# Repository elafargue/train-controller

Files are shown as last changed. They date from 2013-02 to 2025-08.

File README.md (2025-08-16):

train-controller
================

A Z scale model train controller with web interface.

You will find detailed instructions at http://www.aerodynes.org/ . This repository includes both hardware design files and the software you need to build the complete project.

The whole system is working well, and has been running for a long time on an actual layout.

Repository structure:

arduino: arduino sketches for the train controller hardware
hardware: schematics, boards (Eagle)
server: the node.js server that interfaces with the controller and serves the web app

Installation:

Please refer to http://www.aerodynes.org/ for detailed installation instructions. Below is a quick summary:

- Build the cape - Eagle files are included, all components are referenced in the design file, it is fairly straightforward.
- Install the arduino firmware on the cape: you can use the very good "ino" command line interface for doing so.
- Install Ubuntu Linux on your Beaglebone Black
- Install the latest nodejs distribution, and clone this repository
- Install mongodb (Ubuntu package is fine)
- Run "npm install" then "node server.js"
- ... you should be set!

Credits:

Thanks to the creators of the PID and aJson libraries (be sure to use the latest aJson library as I contributed patches to make it more robust).
Thanks to Christophe Coenraets for his great tutorials which were used as a base for the server

License:

All original code is placed under GPLv3 unless stated otherwise, see relevant license files where appropriate.

# Run as a service

Use `resources/train-controller.service` and copy it to `/etc/systemd/system`, then:

```
$ sudo systemctl daemon-reload
$ sudo systemctl enable train-controller
Created symlink /etc/systemd/system/multi-user.target.wants/train-controller.service → /etc/systemd/system/train-controller.service.
$ sudo service train-controller start
```

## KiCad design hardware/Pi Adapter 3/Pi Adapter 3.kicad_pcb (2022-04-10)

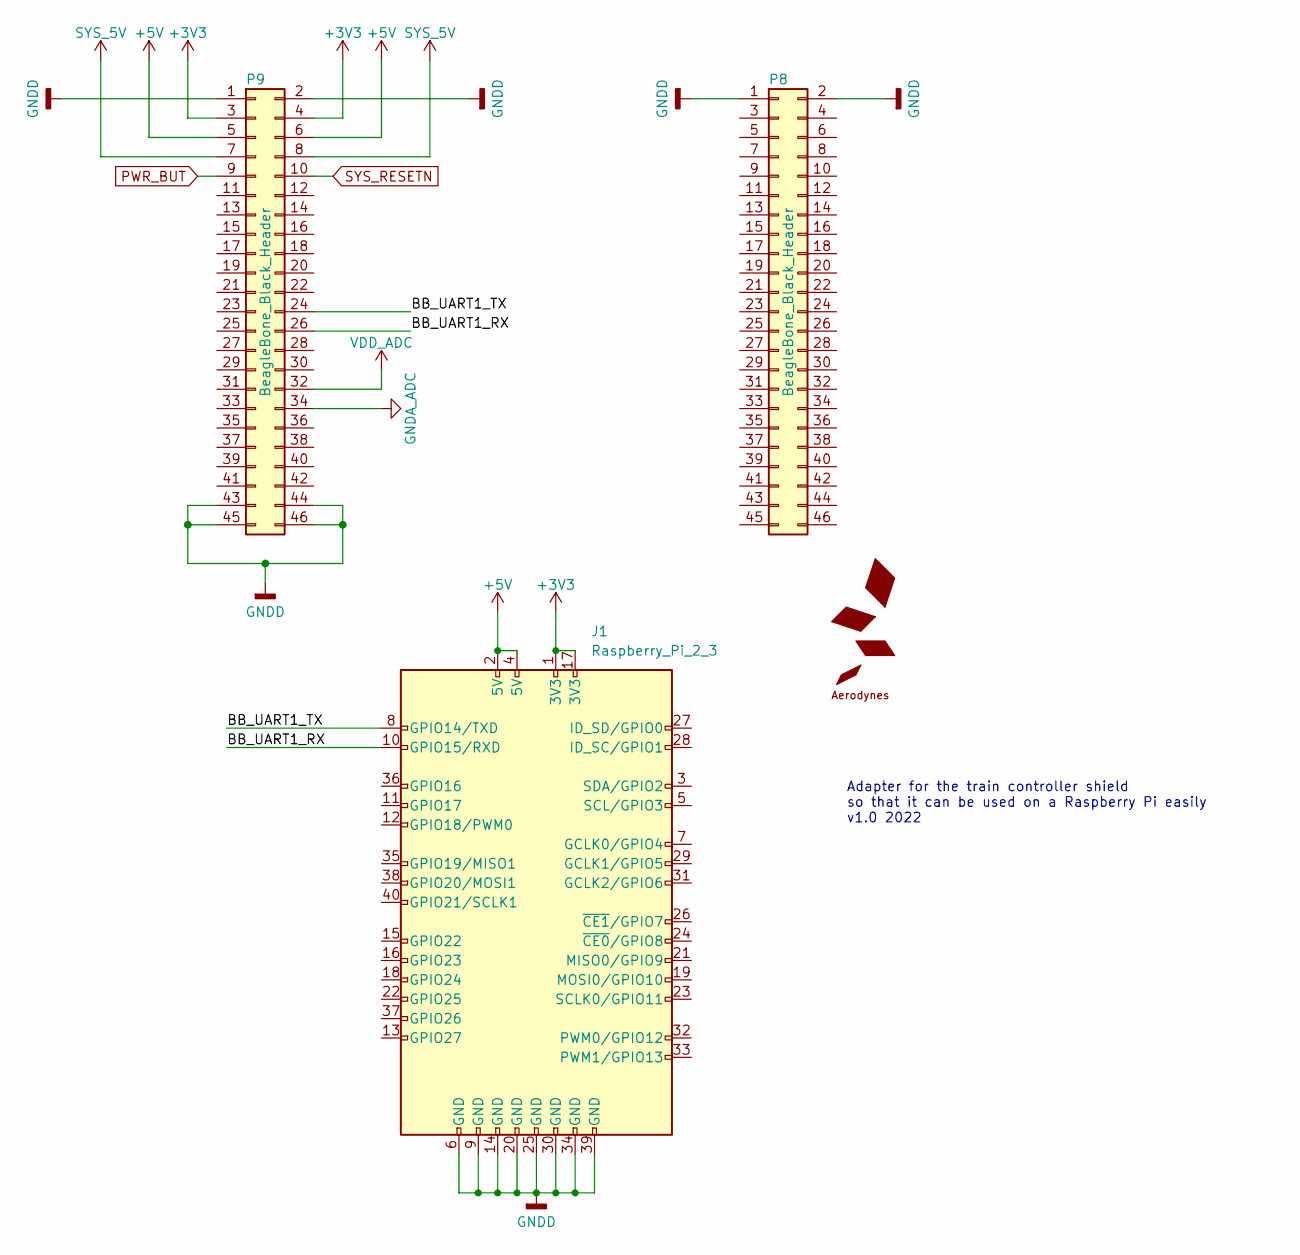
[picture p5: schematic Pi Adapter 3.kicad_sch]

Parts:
J1: Raspberry_Pi_2_3; PinSocket_2x20_P2.54mm_Vertical
M1: LOGO-AERODYNESSMALL; LOGO-AERODYNES-S
P8, P9: BeagleBone_Black_Header; Socket_BeagleBone_Black

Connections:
+3V3: J1.1 (3V3), J1.17 (3V3), P9.3, P9.4
+5V: J1.2 (5V), J1.4 (5V), P9.5, P9.6
/BB_UART1_RX: J1.10 (GPIO15/RXD), P9.26
/BB_UART1_TX: J1.8 (GPIO14/TXD), P9.24
GNDA_ADC: P9.34
GNDD: J1.6 (GND), J1.9 (GND), J1.14 (GND), J1.20 (GND), J1.25 (GND), J1.30 (GND), J1.34 (GND), J1.39 (GND), P8.1, P8.2, P9.1, P9.2, P9.43, P9.44, P9.45, P9.46
PWR_BUT: P9.9
SYS_5V: P9.7, P9.8
SYS_RESETN: P9.10
VDD_ADC: P9.32

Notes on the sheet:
Adapter for the train controller shield so that it can be used on a Raspberry Pi easily v1.0 2022

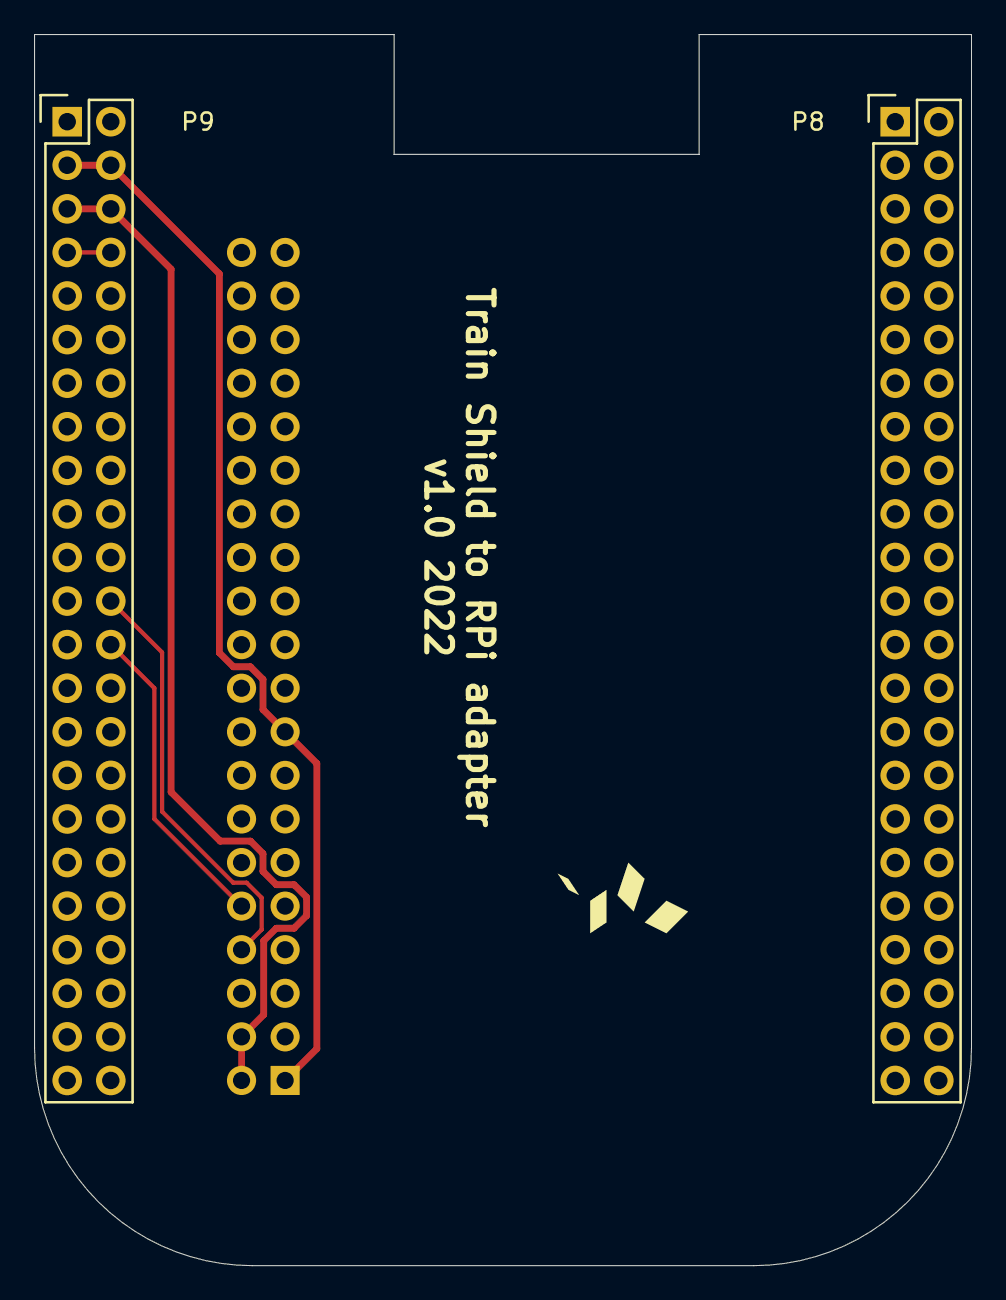
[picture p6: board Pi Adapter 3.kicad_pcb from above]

Board: 2 copper layers, 54.6 x 71.7 mm, 4 parts (1 on the bottom side), 6 nets.

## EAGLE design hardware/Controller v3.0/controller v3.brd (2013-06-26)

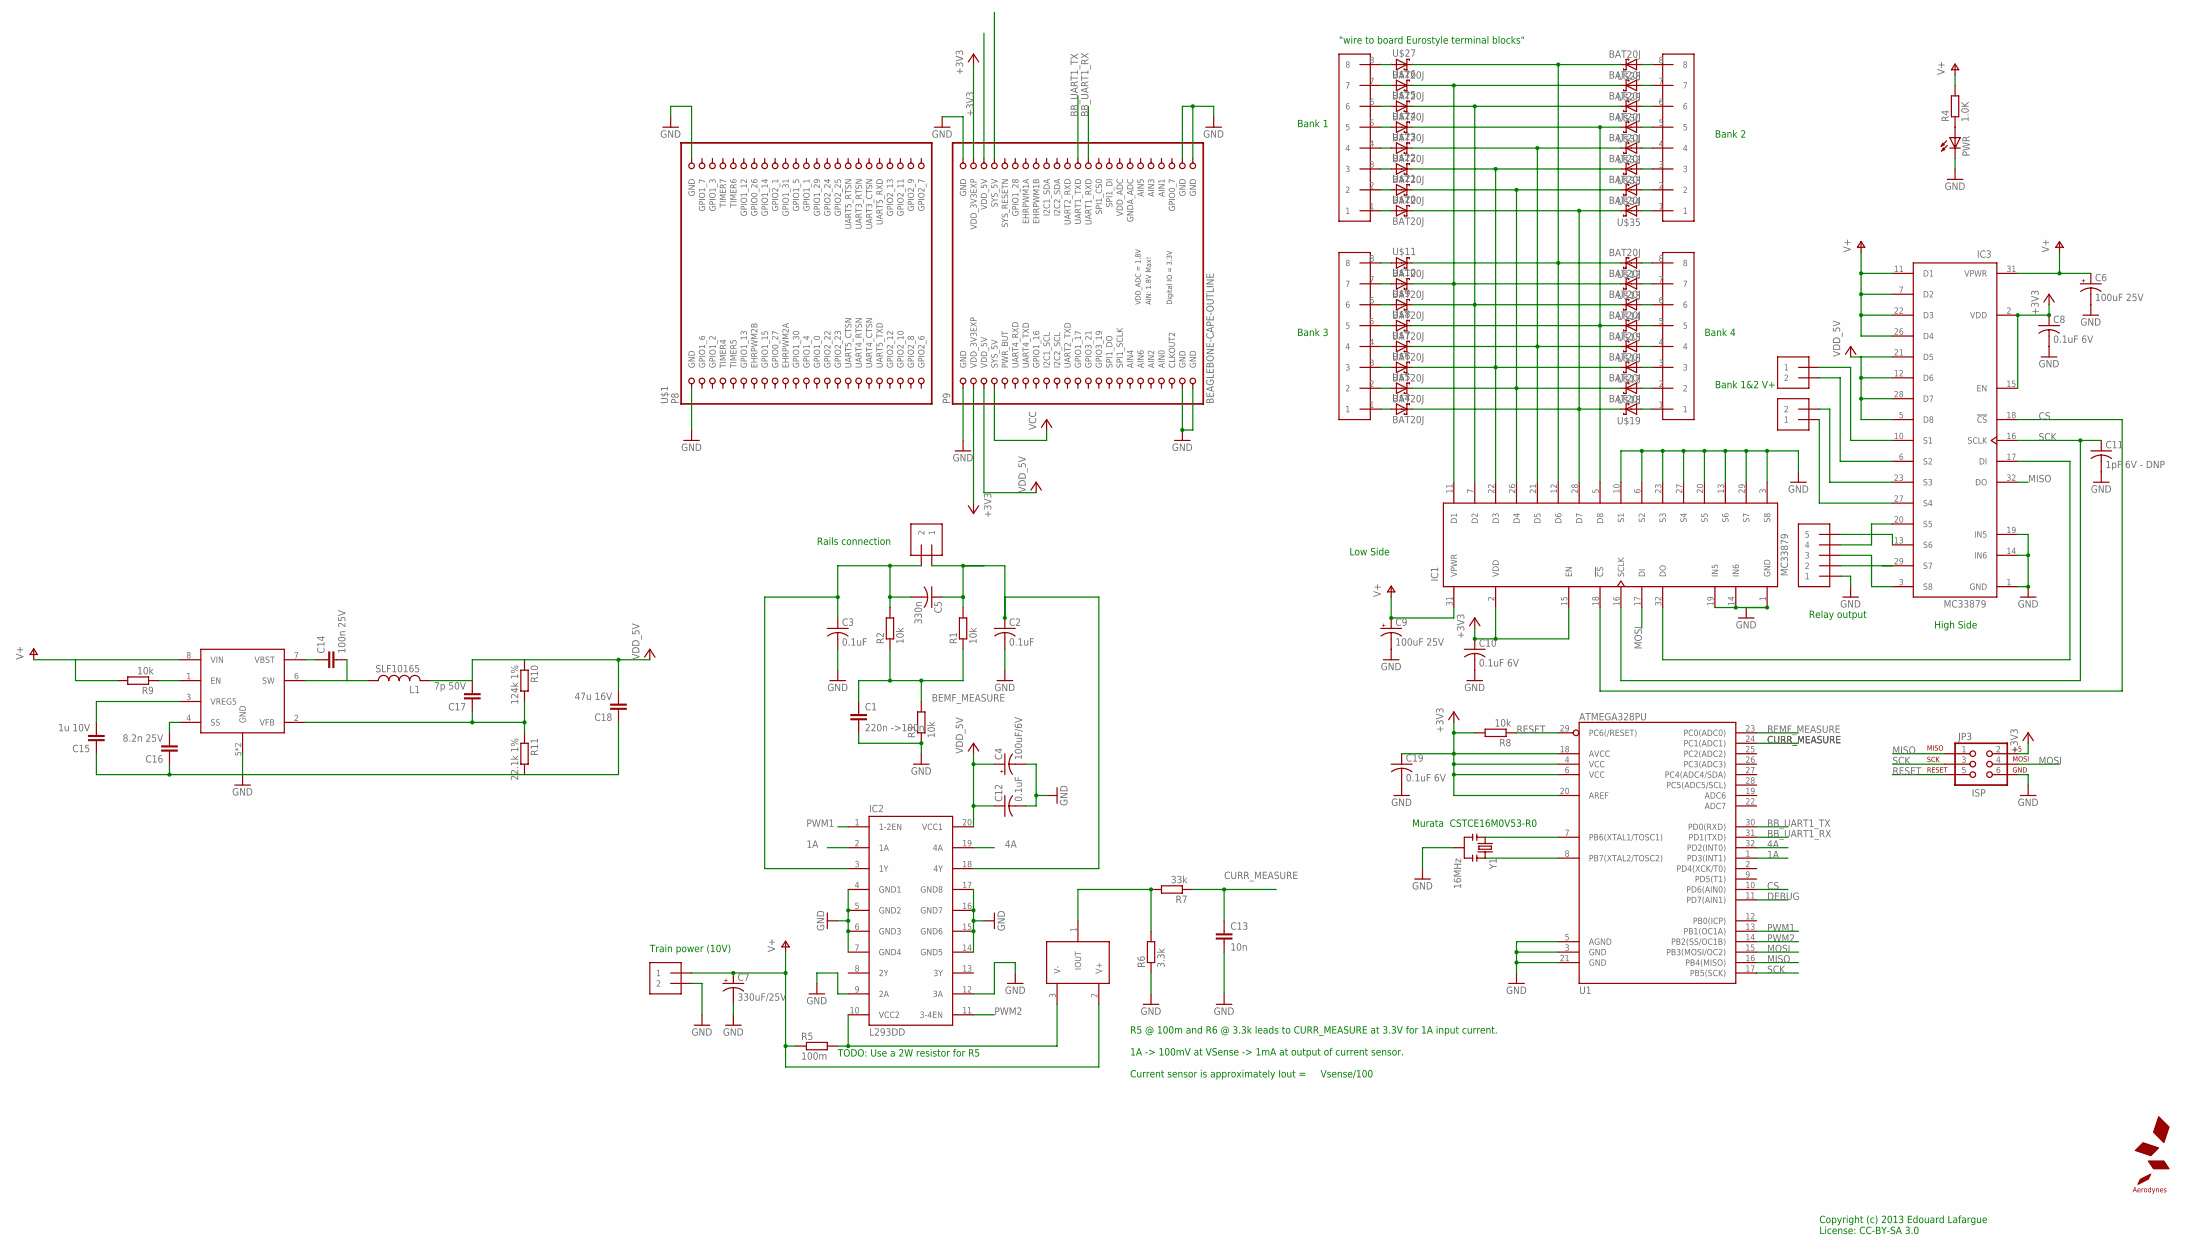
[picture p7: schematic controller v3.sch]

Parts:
BANK12, BANK34: 1X2-3.5MM
C1: 220n ->100n; C0805
C2, C3, C12: 0.1uF; C025-025X050
C4: 100uF/6V; E2,5-5
C5: 330n; C050-025X075
C6, C9: 100uF 25V; E2,5-6E
C7: 330uF/25V; E3,5-8
C8, C10: 0.1uF 6V; C025-025X050
C11: 1pF 6V - DNP; C0805K
C13: 10n; C0805K
C14: 100n 25V; C0805K
C15: 1u 10V; C0603K
C16: 8.2n 25V; C0603K
C17: 7p 50V; C0805K
C18: 47u 16V; C1210K
C19: 0.1uF 6V; C0603K
CON1, CON2, CON3, CON4: 1X08-CONN3.5MM; 1X08-3.5MM
CUR_SENSE: ZXCT1009-F; SOT23-1TOP
IC1, IC3: MC33879; 32SOICW-EP-065PITCH
IC2: L293DD; SOIC20-2
J1: 1X5; 1X05-3.5MM
JP3: ISP; 2X3
L1: SLF10165
PWR: LED3MM
R1, R2, R3, R8, R9: 10k; R0603
R4: 1.0K; R0603
R5: 100m; M1206
R6: 3.3k; R0603
R7: 33k; R0603
R10: 124k 1%; R0603
R11: 22.1k 1%; R0603
SL1, SL2: 1X2-3.5MM
U1: ATMEGA328PU; TQFP32-08
U$1: BEAGLEBONE-CAPE-OUTLINE; BEAGLEBONE_NOCUT
U$2: LOGO-AERODYNESSMALL; LOGO-AERODYNES-S
U$4, U$5, U$6, U$7, U$8, U$9, U$10, U$11, U$12, U$13, U$14, U$15, U$16, U$17, U$18, U$19, U$20, U$21, U$22, U$23, U$24, U$25, U$26, U$27, U$28, U$29, U$30, U$31, U$32, U$33, U$34, U$35: BAT20J; SOD-323F
U$36: TPS54327DDA; SOIC8-DDA
Y1: 16MHz; RESONATOR-SMD

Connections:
1A: IC2.2 (1A), U1.1 (PD3(INT1))
1Y: C3.1, C5.2, IC2.3 (1Y), R2.2, SL1.2
4A: IC2.19 (4A), U1.32 (PD2(INT0))
4Y: C2.1, C5.1, IC2.18 (4Y), R1.2, SL1.1
+3V3: C8.1, C10.1, C19.1, IC1.2 (VDD), IC1.15 (EN), IC3.2 (VDD), IC3.15 (EN), JP3.2, R8.2, U1.4 (VCC), U1.6 (VCC), U1.18 (AVCC), U1.20 (AREF), U$1.P9-3 (VDD_3V3EXP), U$1.P9-4 (VDD_3V3EXP)
BB_UART1_RX: U1.31 (PD1(TXD)), U$1.P9-26 (UART1_RXD)
BB_UART1_TX: U1.30 (PD0(RXD)), U$1.P9-24 (UART1_TXD)
BEMF_MEASURE: C1.1, R1.1, R2.1, R3.2, U1.23 (PC0(ADC0))
CS: IC1.18 (!CS), IC3.18 (!CS), U1.10 (PD6(AIN0))
CURR_MEASURE: C13.1, R7.1, U1.24 (PC1(ADC1))
DEBUG: U1.11 (PD7(AIN1))
GND: C1.2, C2.2, C3.2, C4.-, C6.-, C7.-, C8.2, C9.-, C10.2, C11.2, C12.2, C13.2, C15.1, C16.1, C18.1, C19.2, IC1.1 (GND), IC1.3 (S8), IC1.6 (S2), IC1.10 (S1), IC1.13 (S6), IC1.14 (IN6), IC1.19 (IN5), IC1.20 (S5), IC1.23 (S3), IC1.27 (S4), IC1.29 (S7), IC2.4 (GND1), IC2.5 (GND2), IC2.6 (GND3), IC2.7 (GND4), IC2.9 (2A), IC2.12 (3A), IC2.14 (GND5), IC2.15 (GND6), IC2.16 (GND7), IC2.17 (GND8), IC3.1 (GND), IC3.14 (IN6), IC3.19 (IN5), J1.1, JP3.6, PWR.K (C), R3.1, R6.1, R11.2, SL2.2, U1.3 (GND), U1.5 (AGND), U1.21 (GND), U$1.P8-1 (GND), U$1.P8-2 (GND), U$1.P9-1 (GND), U$1.P9-2 (GND), U$1.P9-43 (GND), U$1.P9-44 (GND), U$1.P9-45 (GND), U$1.P9-46 (GND), U$36.5 (GND), U$36.PAD (GND), Y1.2
GNDA_ADC: U$1.P9-34 (GNDA_ADC)
MISO: IC3.32 (DO), JP3.1, U1.16 (PB4(MISO))
MOSI: IC1.17 (DI), JP3.4, U1.15 (PB3(MOSI/OC2))
unnamed: BANK34.1, IC3.27 (S4)
unnamed: BANK34.2, IC3.23 (S3)
unnamed: BANK12.2, IC3.6 (S2)
unnamed: BANK12.1, IC3.10 (S1)
unnamed: CUR_SENSE.3 (V-), IC2.10 (VCC2), R5.2
unnamed: CUR_SENSE.1 (IOUT), R6.2, R7.2
unnamed: IC1.22 (D3), U$6.C, U$17.C, U$22.C, U$33.C
unnamed: IC1.21 (D5), U$7.C, U$16.C, U$23.C, U$32.C
unnamed: IC1.5 (D8), U$8.C, U$15.C, U$24.C, U$31.C
unnamed: CON3.3, U$6.A
unnamed: IC1.28 (D7), U$4.C, U$19.C, U$20.C, U$35.C
unnamed: IC1.12 (D6), U$11.C, U$12.C, U$27.C, U$28.C
unnamed: IC1.32 (DO), IC3.17 (DI)
unnamed: IC1.11 (D1), U$10.C, U$13.C, U$26.C, U$29.C
unnamed: IC1.26 (D4), U$5.C, U$18.C, U$21.C, U$34.C
unnamed: IC1.7 (D2), U$9.C, U$14.C, U$25.C, U$30.C
unnamed: IC3.20 (S5), J1.4
unnamed: CON3.2, U$5.A
unnamed: CON3.1, U$4.A
unnamed: CON3.8, U$11.A
unnamed: CON3.7, U$10.A
unnamed: CON3.6, U$9.A
unnamed: CON3.5, U$8.A
unnamed: CON3.4, U$7.A
unnamed: CON4.8, U$12.A
unnamed: CON4.7, U$13.A
unnamed: CON4.6, U$14.A
unnamed: CON4.5, U$15.A
unnamed: CON4.4, U$16.A
unnamed: CON4.3, U$17.A
unnamed: CON4.2, U$18.A
unnamed: CON4.1, U$19.A
unnamed: CON1.8, U$27.A
unnamed: CON1.7, U$26.A
unnamed: PWR.A, R4.1
unnamed: CON1.6, U$25.A
unnamed: CON1.5, U$24.A
unnamed: CON1.4, U$23.A
unnamed: CON1.3, U$22.A
unnamed: CON1.2, U$21.A
unnamed: CON1.1, U$20.A
unnamed: CON2.8, U$28.A
unnamed: CON2.7, U$29.A
unnamed: CON2.6, U$30.A
unnamed: CON2.5, U$31.A
unnamed: CON2.4, U$32.A
unnamed: CON2.3, U$33.A
unnamed: CON2.2, U$34.A
unnamed: CON2.1, U$35.A
unnamed: IC3.13 (S6), J1.5
unnamed: IC3.29 (S7), J1.2
unnamed: IC3.3 (S8), J1.3
unnamed: U1.7 (PB6(XTAL1/TOSC1)), Y1.1
unnamed: U1.8 (PB7(XTAL2/TOSC2)), Y1.3
unnamed: R9.1, U$36.1 (EN)
unnamed: C14.1, U$36.7 (VBST)
unnamed: C16.2, U$36.4 (SS)
unnamed: C14.2, L1.P$1 (1), U$36.6 (SW)
unnamed: C15.2, U$36.3 (VREG5)
unnamed: C17.1, R10.2, R11.1, U$36.2 (VFB)
PWM1: IC2.1 (1-2EN), U1.13 (PB1(OC1A))
PWM2: IC2.11 (3-4EN), U1.14 (PB2(SS/OC1B))
RESET: JP3.5, R8.1, U1.29 (PC6(/RESET))
SCK: C11.1, IC1.16 (SCLK), IC3.16 (SCLK), JP3.3, U1.17 (PB5(SCK))
SYS_5V: U$1.P9-7 (SYS_5V), U$1.P9-8 (SYS_5V)
V+: C6.+, C7.+, C9.+, CUR_SENSE.2 (V+), IC1.31 (VPWR), IC3.7 (D2), IC3.11 (D1), IC3.22 (D3), IC3.26 (D4), IC3.31 (VPWR), R4.2, R5.1, R9.2, SL2.1, U$36.8 (VIN)
VDD_5V: C4.+, C12.1, C17.2, C18.2, IC2.20 (VCC1), IC3.5 (D8), IC3.12 (D6), IC3.21 (D5), IC3.28 (D7), L1.P$2 (2), R10.1, U$1.P9-5 (VDD_5V), U$1.P9-6 (VDD_5V)
VDD_ADC: U$1.P9-32 (VDD_ADC)

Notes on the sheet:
Rails connection
Train power (10V)
Low Side
High Side
Bank 1
Bank 2
Bank 1&2 V+
Bank 3
Bank 4
"wire to board Eurostyle terminal blocks"
R5 @ 100m and R6 @ 3.3k leads to CURR_MEASURE at 3.3V for 1A input current. 1A -> 100mV at VSense -> 1mA at output of current sensor. Current sensor is approximately Iout = Vsense/100
Copyright (c) 2013 Edouard Lafargue License: CC-BY-SA 3.0
TODO: Use a 2W resistor for R5
Relay output
Murata CSTCE16M0V53-R0

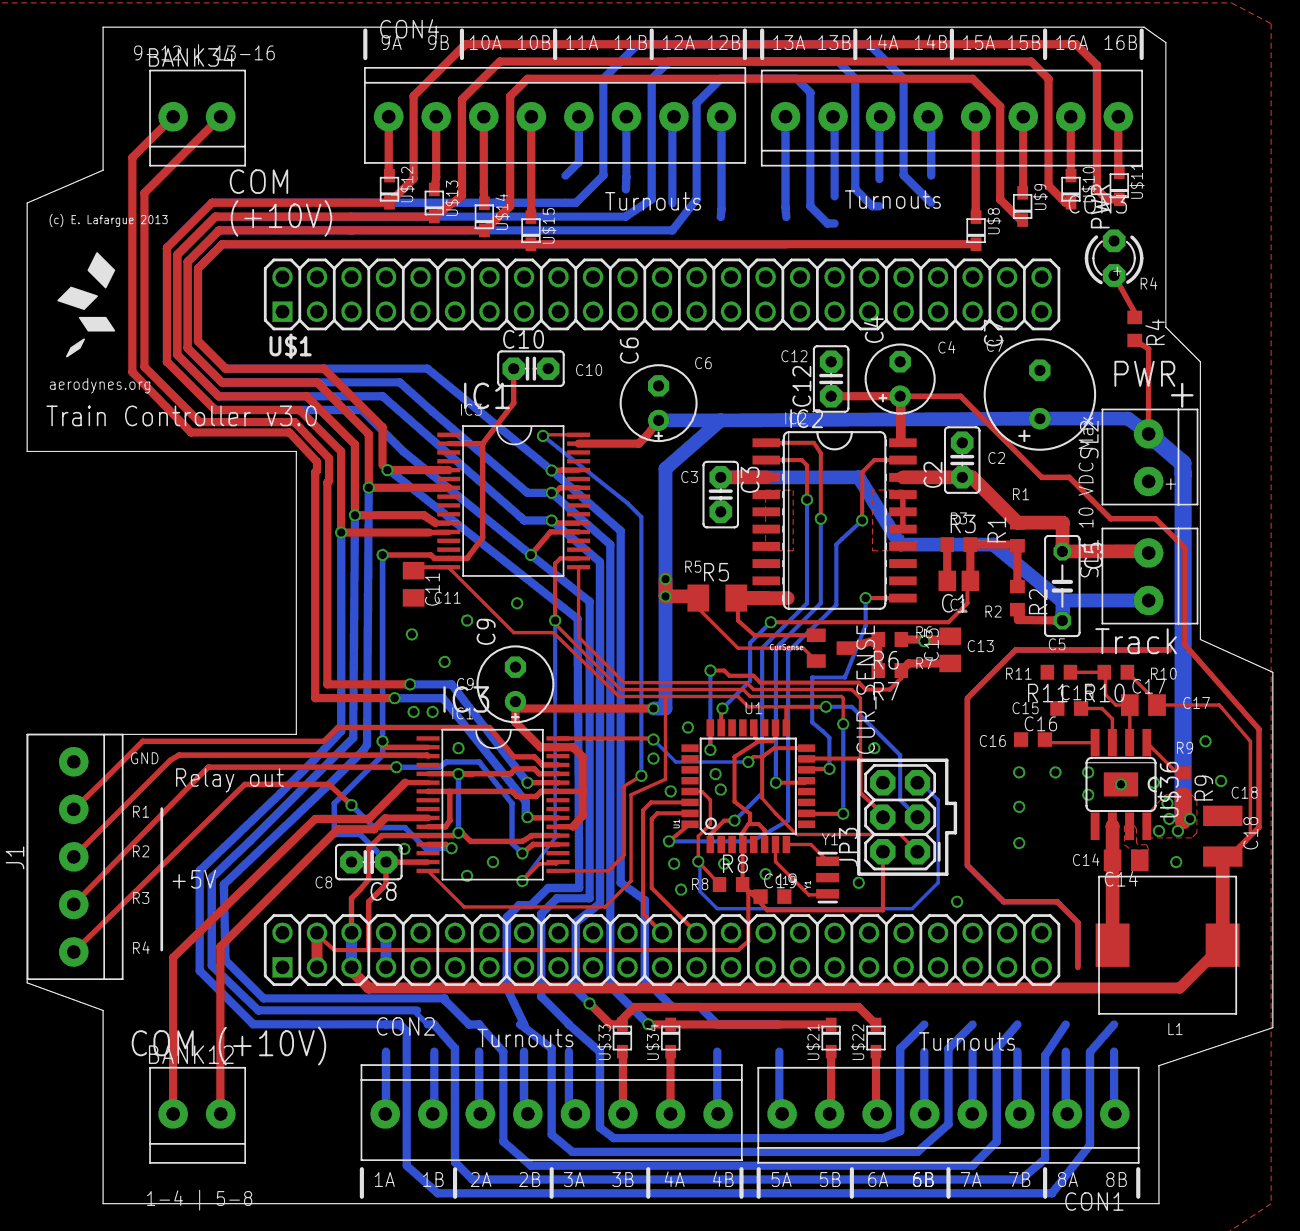
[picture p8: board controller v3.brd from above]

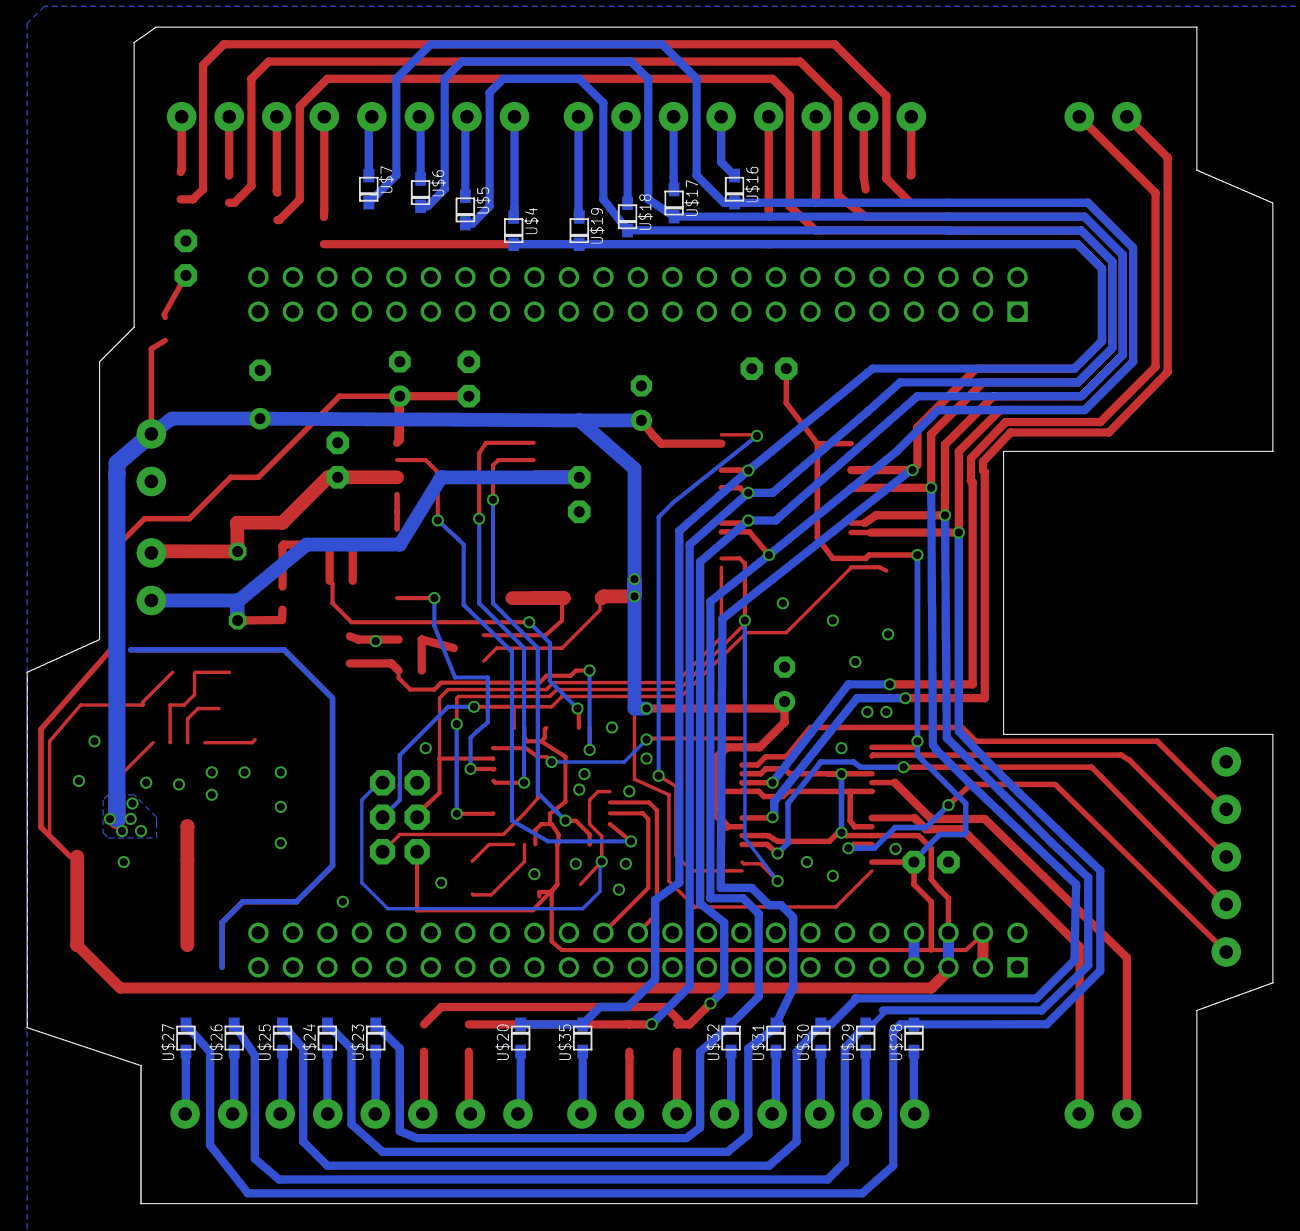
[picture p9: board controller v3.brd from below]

Board: 2 copper layers, 91.7 x 86.6 mm, 83 parts (20 on the bottom side), 80 nets.

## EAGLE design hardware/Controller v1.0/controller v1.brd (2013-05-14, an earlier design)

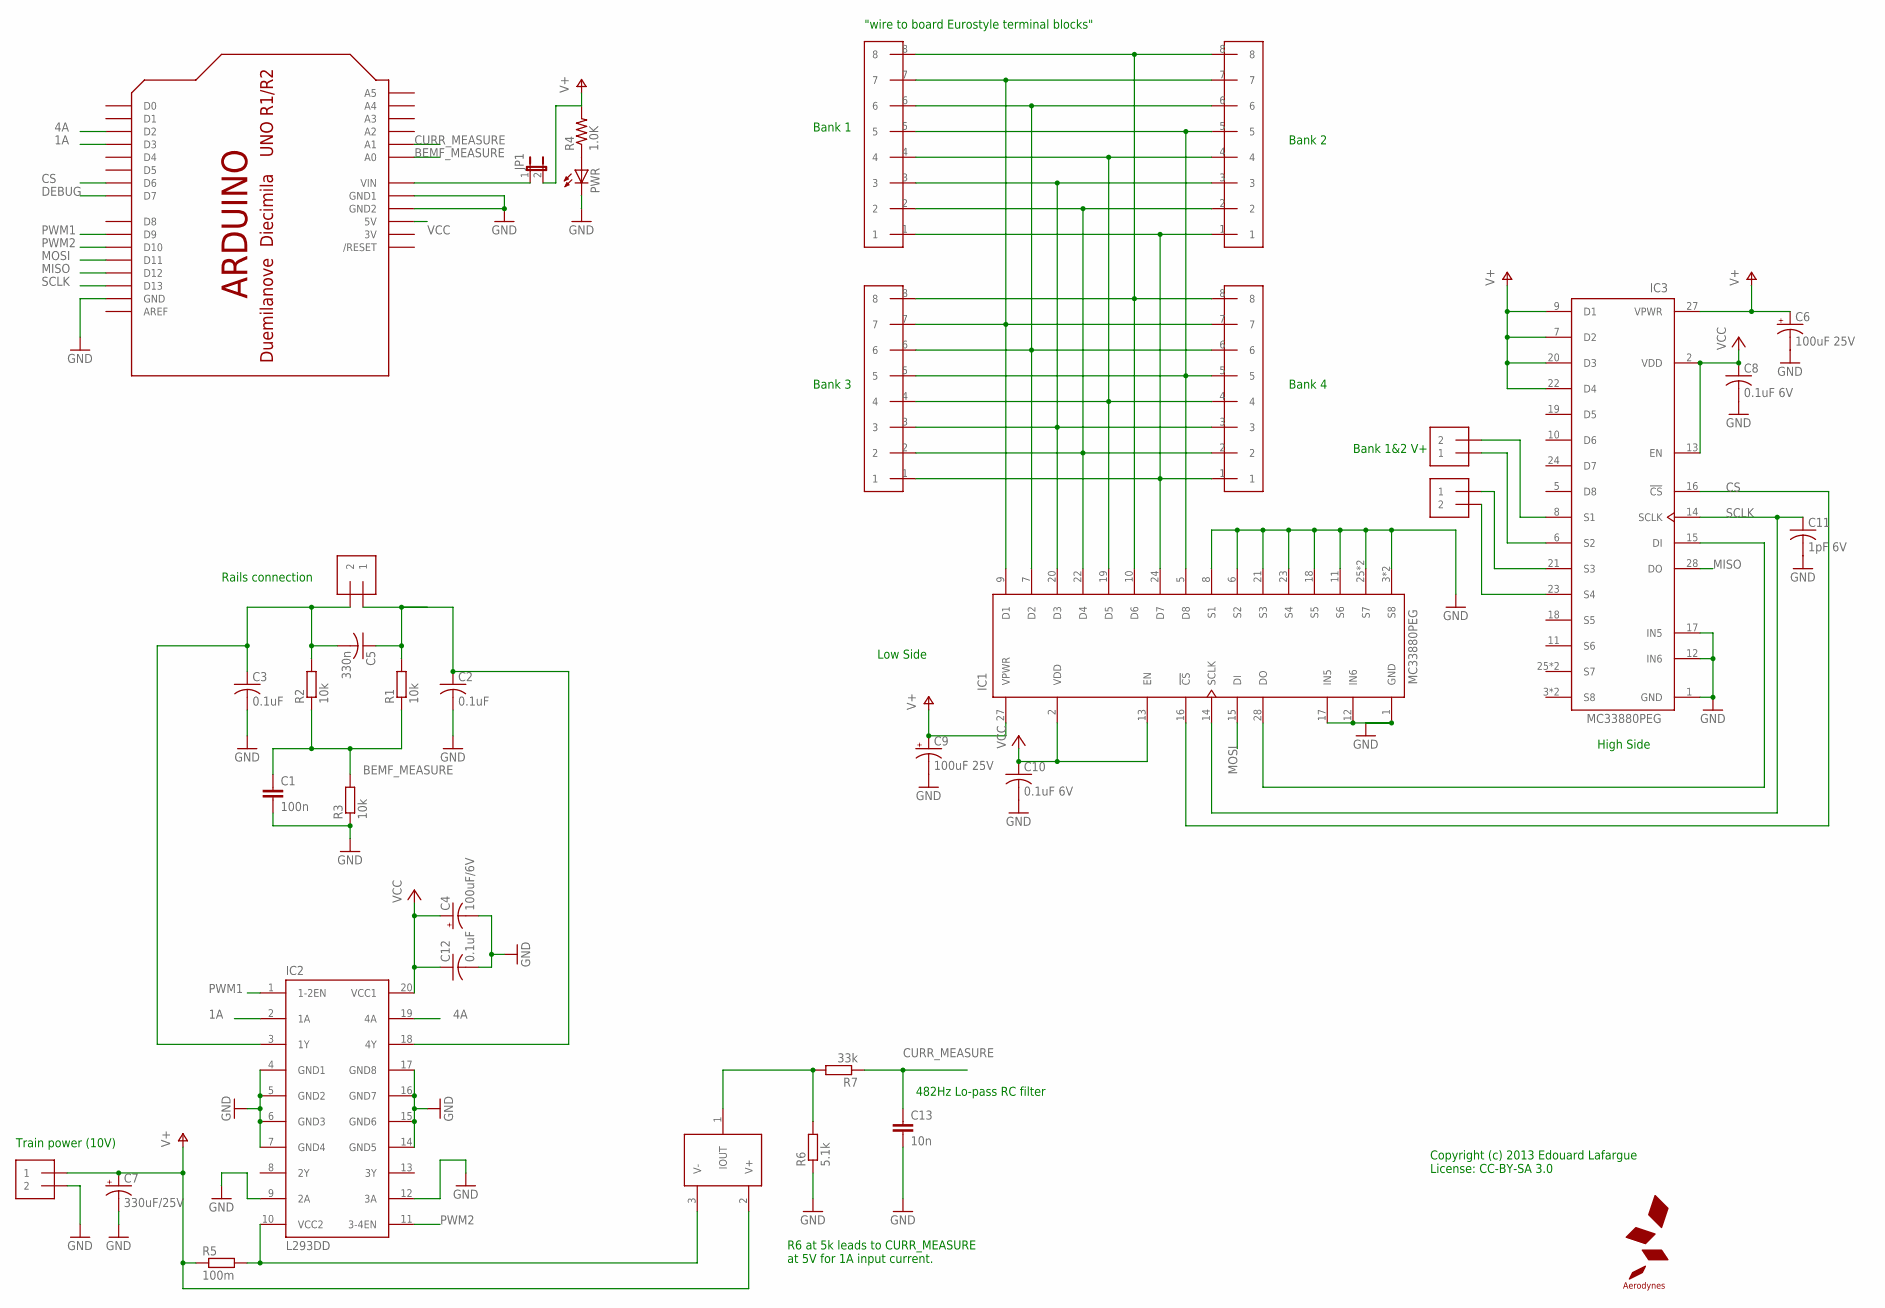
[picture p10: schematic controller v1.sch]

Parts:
BANK12, BANK34: 1X2-3.5MM
C1: 100n; C0805
C2, C3, C12: 0.1uF; C025-025X050
C4: 100uF/6V; E2,5-5
C5: 330n; C050-025X075
C6, C9: 100uF 25V; E2,5-6E
C7: 330uF/25V; E2,5-6
C8, C10: 0.1uF 6V; C025-025X050
C11: 1pF 6V; C0805K
C13: 10n; C0805K
CON1, CON2, CON3, CON4: 1X08-CONN3.5MM; 1X08-3.5MM
IC1, IC3: MC33880PEG; SO28W
IC2: L293DD; SOIC20-2
JP1: JP1E; JP1
PWR: LED3MM
R1, R2, R3: 10k; R0805
R4: 1.0K; M0805
R5: 100m; M1206
R6: 5.1k; R0603
R7: 33k; R0603
SL1, SL2: 1X2-3.5MM
U$1: ARDUINO; ARDUINO-NOCUT
U$2: LOGO-AERODYNESSMALL; LOGO-AERODYNES-S
U$3: ZXCT1009-F; SOT23-1TOP

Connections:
1A: IC2.2 (1A), U$1.D3
1Y: C3.1, C5.2, IC2.3 (1Y), R2.2, SL1.2
3V: U$1.3V
4A: IC2.19 (4A), U$1.D2
4Y: C2.1, C5.1, IC2.18 (4Y), R1.2, SL1.1
BEMF_MEASURE: C1.1, R1.1, R2.1, R3.2, U$1.A0
CS: IC1.16 (!CS), IC3.16 (!CS), U$1.D6
CURR_MEASURE: C13.1, R7.1, U$1.A1
DEBUG: U$1.D7
GND: C1.2, C2.2, C3.2, C4.-, C6.-, C7.-, C8.2, C9.-, C10.2, C11.2, C12.2, C13.2, IC1.1 (GND), IC1.3 (S8), IC1.4 (S8), IC1.6 (S2), IC1.8 (S1), IC1.11 (S6), IC1.12 (IN6), IC1.17 (IN5), IC1.18 (S5), IC1.21 (S3), IC1.23 (S4), IC1.25 (S7), IC1.26 (S7), IC2.4 (GND1), IC2.5 (GND2), IC2.6 (GND3), IC2.7 (GND4), IC2.9 (2A), IC2.12 (3A), IC2.14 (GND5), IC2.15 (GND6), IC2.16 (GND7), IC2.17 (GND8), IC3.1 (GND), IC3.12 (IN6), IC3.17 (IN5), PWR.K (C), R3.1, R6.1, SL2.2, U$1.GND, U$1.GND1, U$1.GND2
MISO: IC3.28 (DO), U$1.D12
MOSI: IC1.15 (DI), U$1.D11
unnamed: BANK34.2, IC3.23 (S4)
unnamed: BANK34.1, IC3.21 (S3)
unnamed: BANK12.1, IC3.6 (S2)
unnamed: BANK12.2, IC3.8 (S1)
unnamed: IC2.10 (VCC2), R5.2, U$3.3 (V-)
unnamed: R6.2, R7.2, U$3.1 (IOUT)
unnamed: CON1.3, CON2.3, CON3.3, CON4.3, IC1.20 (D3)
unnamed: CON1.4, CON2.4, CON3.4, CON4.4, IC1.19 (D5)
unnamed: CON1.5, CON2.5, CON3.5, CON4.5, IC1.5 (D8)
unnamed: JP1.1, U$1.VIN
unnamed: CON1.1, CON2.1, CON3.1, CON4.1, IC1.24 (D7)
unnamed: CON1.8, CON2.8, CON3.8, CON4.8, IC1.10 (D6)
unnamed: IC1.28 (DO), IC3.15 (DI)
unnamed: CON1.7, CON2.7, CON3.7, CON4.7, IC1.9 (D1)
unnamed: CON1.2, CON2.2, CON3.2, CON4.2, IC1.22 (D4)
unnamed: CON1.6, CON2.6, CON3.6, CON4.6, IC1.7 (D2)
unnamed: PWR.A, R4.1
PWM1: IC2.1 (1-2EN), U$1.D9
PWM2: IC2.11 (3-4EN), U$1.D10
SCLK: C11.1, IC1.14 (SCLK), IC3.14 (SCLK), U$1.D13
V+: C6.+, C7.+, C9.+, IC1.27 (VPWR), IC3.7 (D2), IC3.9 (D1), IC3.20 (D3), IC3.22 (D4), IC3.27 (VPWR), JP1.2, R4.2, R5.1, SL2.1, U$3.2 (V+)
VCC: C4.+, C8.1, C10.1, C12.1, IC1.2 (VDD), IC1.13 (EN), IC2.20 (VCC1), IC3.2 (VDD), IC3.13 (EN), U$1.5V

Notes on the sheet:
Rails connection
Train power (10V)
Low Side
High Side
Bank 1
Bank 2
Bank 1&2 V+
Bank 3
Bank 4
"wire to board Eurostyle terminal blocks"
R6 at 5k leads to CURR_MEASURE at 5V for 1A input current.
Copyright (c) 2013 Edouard Lafargue License: CC-BY-SA 3.0
482Hz Lo-pass RC filter

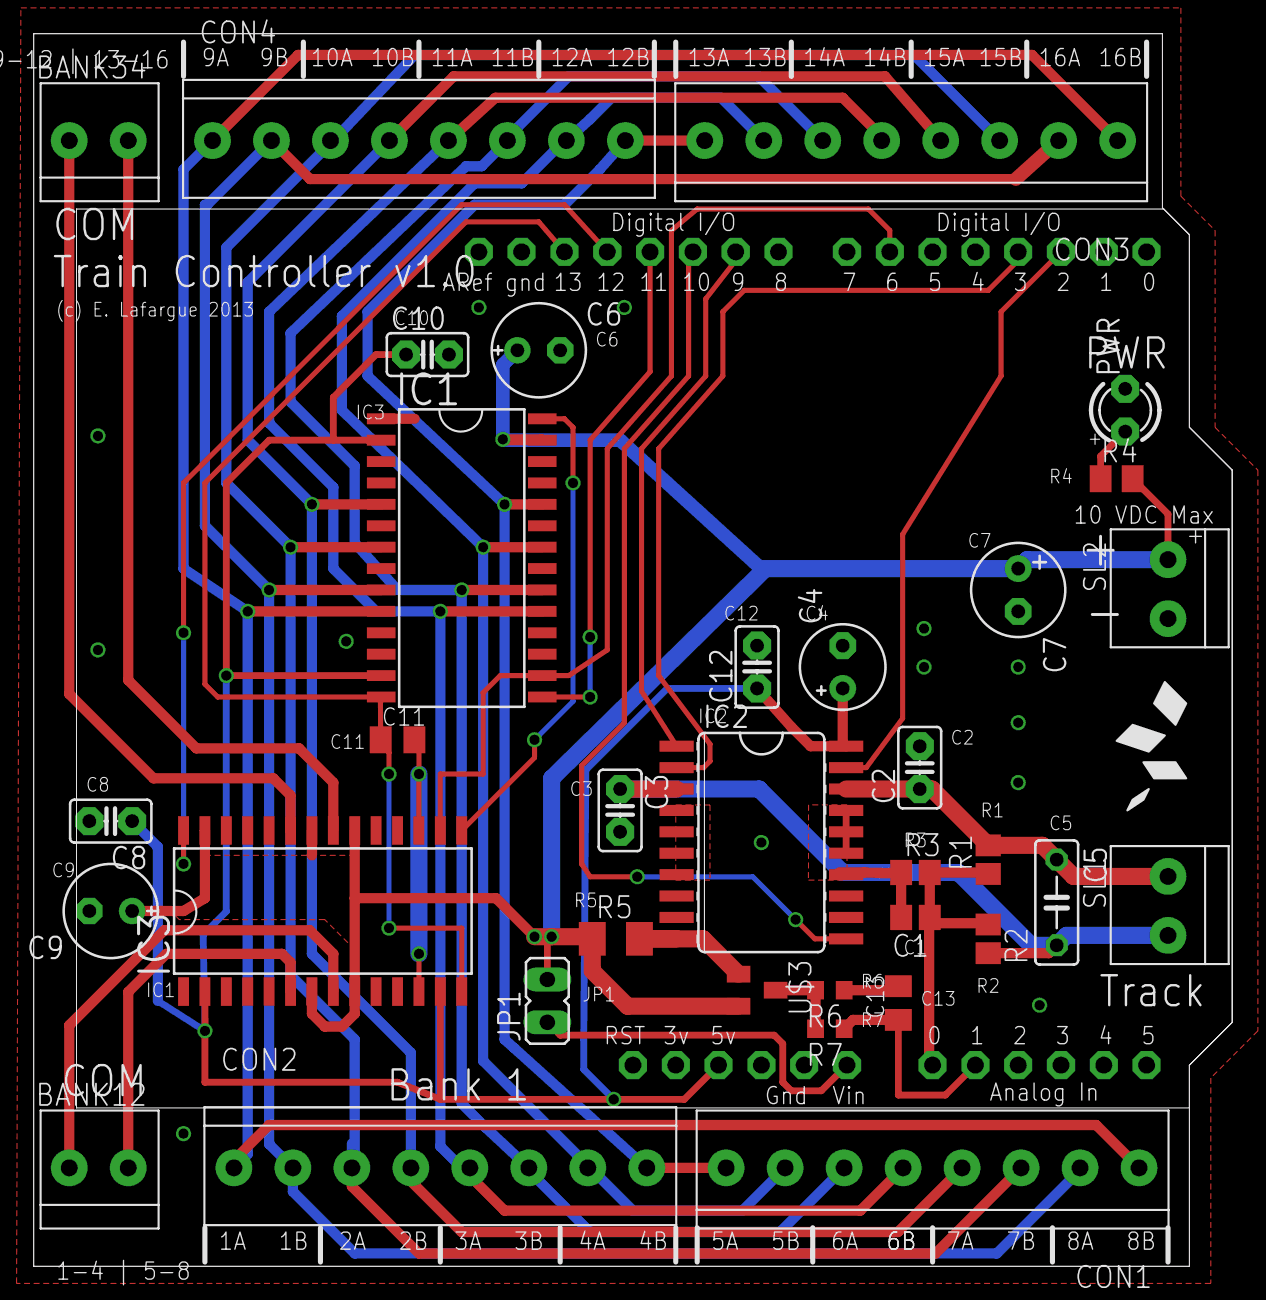
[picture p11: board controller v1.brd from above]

Board: 2 copper layers, 71.1 x 73.1 mm, 36 parts (0 on the bottom side), 32 nets.

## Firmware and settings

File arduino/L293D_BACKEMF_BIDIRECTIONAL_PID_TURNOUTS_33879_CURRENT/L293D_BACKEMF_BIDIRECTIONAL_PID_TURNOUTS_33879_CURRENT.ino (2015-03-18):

/**
 * This is a Z-scale integrated train and turnout controller, with a serial
 * port JSON interface. It features backward/forward driving of one locomotive
 * with speed regulation, and control of up to 16 turnouts or up to 32 
 * single solenoid accessories.
 *
 *  TODO:
 *    - implement proper digital filtering rather than rolling averages
 *
 * 2013.03.06: add SPI library to control a 75HC595 for quick prototyping
 * 2013.03.16: use two MC33880 for control of up to 16 accessories
 * 2013.05.12: Add current measurement support
 * 2013.06.23: Add support for MC33879 rather than MC33880
 * 2013.06.25: Add command to trigger a software reset
 * 2013.06.27: Add commands to control relays that are present on v3.0 controller
 * 2015.03.18: Accessory Auto off: tests and bugfix (works fine now)
 *
 * (c) 2013 Edouard Lafargue, edouard@lafargue.name
 *
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
 */
 
/* We use the Timer1 library to get more options on PWM frequency and interrupts*/
#include <TimerOne.h>
/* The PID library is a nice implementation of PID calculations, no need to reinvent the wheel */
#include <PID_v1.h>
/* We use the Arduino JSON library to talk to our server over the serial line */
/* Be sure to use the latest version as I added patches to make the library more error-tolerant */
#include <aJSON.h>
/* The hardware SPI library is used to control turnouts */
#include <SPI.h>

//////////////////////////////////////////////////////////////////
// Enable Debug mode
//////////////////////////////////////////////////////////////////
#define DEBUG

//////////////////////////////////////////////////////////////////
// Hardware pinout info
//////////////////////////////////////////////////////////////////

// How the L293D H Bridge is connected to the Arduino
const int fwdpwm = 9;  // Used for PWM, L293D EN1
const int bckpwm = 10; // Used for PWM, L293D EN2
const int pin1a = 3;   // Pin 1A
const int pin4a = 2;   // Pin 4A
const int bemfpin = 0; // Analog0 Pin connected to BEMF measurement point
const int currentpin = 1; // Analog1 Pin connected to current measurement chip.

// Connect GND, VCC1 and VCC2 on the L293D
// Motor connected to Y1 and Y4

#ifdef DEBUG
const int debugpin = 7; // This is connected to a scope to check the speed
                        // of the interrupt routine for BEMF measurement
#endif
//////////////////////////////////////////////////////////////////
// Global constants and defines
//////////////////////////////////////////////////////////////////

// Define two set/clear macros to do PIN manipulation
// way way faster than Arduino's digitalWrite.
// inspired by the the _BV() macro
#define setpin(port, pin) (port) |= (1 << (pin)) 
#define clearpin(port, pin) (port) &= ~(1 << (pin))

// Direction of the train
#define STOP 0
#define FWD  1
#define BCK  2

// Types of messages that can be output (internal codes)
#define MSG_NOP 0
#define MSG_PID_VALUES 1
#define MSG_ACCP_VALUE 2
#define MSG_ACCM_VALUE 3
#define MSG_UPDT_VALUE 4
#define MSG_TURNOUTS_VALUE 5
#define MSG_POST_VALUE 6
#define MSG_FAULT_VALUES 7
#define MSG_RELAYS_VALUE 8
#define MSG_ACK 98          // Sent to acknowlege a command
#define MSG_ERROR 99        // Sent to tell command error
#define MSG_JSON_SYNTAX 100 // JSON Syntax error

// We are able to run a few autotests at startup,
// result codes are defined here:
#define SPI_INTEGRITY_FAULT 1  // Issue on SPI bus

// ADC Prescaler values to force the ADC to a faster mode
const unsigned char PS_16 = (1 << ADPS2);
const unsigned char PS_32 = (1 << ADPS2) | (1 << ADPS0);
const unsigned char PS_64 = (1 << ADPS2) | (1 << ADPS1);
const unsigned char PS_128 = (1 << ADPS2) | (1 << ADPS1) | (1 << ADPS0);

// Turnout control below
#define OP_PULSE 0
#define OP_ON    1
#define OP_OFF   2

// Relays: the v3.0 controller supports 4 relays, we
// set those and related operations as defines here:
#define RELAYS 4
#define RELAY_ON 1
#define RELAY_OFF 0


// SPI Connection to the shift register/relay driver
const int spi_mosi  = 11;
const int spi_miso  = 12;
const int spi_clock = 13;
const int spi_ss    =  6;

const int turnout_max   = 16; // 1 x MC33879 = 8 ports = 4 turnouts
const int turnout_banks =  4; // We have 4 banks of 4 turnouts

//////////////////////////////////////////////////////////////////
// Global Variables
//////////////////////////////////////////////////////////////////

double pwm_rate = 0;
double target_rpm = 0;
int current_direction = STOP;

byte relay_mask = 0; // A mask to keep the state of relay outputs when we manipulate turnouts

// Back EMF Measurement: we do a rolling average over BUFFER_SIZE samples which
// we keep in a ring buffer because BEMF measurement is extremely noisy
// on tiny locomotives.
#define BUFFER_SIZE 48
double ring_buffer [BUFFER_SIZE];
double ring_buffer_current [BUFFER_SIZE];
int idx = 0;
int idx2 = 0;
double measured_rpm = 0;
double measured_current = 0;

aJsonStream serial_stream(&Serial);
unsigned long last_print; // time when we last output a status message or response
unsigned long fr_print;
int next_message; // ID of next message to output
const char* ack_cmd;    // command we are acknowledging for.

// Accessory global variables
double accessory_on_timestamp = 0;    // On time stamp
int accessory_on_id   = -1;           // ID of accessory that was turned on
int accessory_on_port =  0;

// In order to simplify PCB layout, I used MC33880 pins out of order,
// so I'm using a static mapping array to remap the pins for both
// turnouts and banks:
// Turnout bank mapping: what pin matches what port
//                            Port:    0    1    2    3    4   5   6   7 

const byte lowside_map[]          = {  6,   3,   2,   4,   7,  1,  0,  5 };
const byte lowside_inverse_map[] =  {  6,   5,   2,   1,   3,  7,  0,  4 };

// Turnout pinout mapping
//                  Port:    0    1    2    3
const byte highside_map[] = {  1,   0,   2,   3};

// Relay output mapping
const byte relay_map[] = { 2, 3, 0, 1};

// Connection map: for port 1 to 32
// false: accessory not connected
// true: accessory connected
#define ACCESSORY_PORTS 32
int accessory_map[ACCESSORY_PORTS];


// Auto-test of the board at startup:
byte post_result = 0;

//////////////////////////////////////////////////////////////////
// Default controller settings (powerup settings)
//////////////////////////////////////////////////////////////////

// The two below cannot be modified for now:
const int PWMFREQUENCY = 60; // 60Hz frequency for PWM output.
const int MAX_PWM = 800;

//Specify the links and initial tuning parameters
//
// Note: shall we use two sets, one agressive for honing in, and a conservative
//       for keeping at the point ?
//double Kp=2, Ki=1.5, Kd=1;
//double Kp=1.15,Ki=0.35, Kd=0.00;
//double Kp=0.25,Ki=1.31, Kd=0.42;
//double Kp=0.05, Ki=1.35, Kd=0.38;

// Very good results with those:
double Kp=0.40, Ki=1.45, Kd=0;

// We need a fast running loop, because the trains are
// very lightweight, so their speed changes very fast when
// any perturbation occurs.
int sampleTime = 80; // Lower than 80 is shorter than the loop, so the PID calculations
                     // will be wrong, don't go lower than this.

// Default controller serial update rate (in ms)
int updateRate = 300;

// Default length of Turnout set pulse (in ms):
int turnoutPulse = 20;
// Default maximum "on" time for accessory
int turnoutMaxOn = 2000;

/**
 * Arguments are myPID(Input,Output,Setpoint,kp,ki,kd,mode);
 *   Input : The variable we're trying to control -> Measured speed of the train
 *   Output: The variable that will be adjusted by the pid -> pwm_rate
 * Setpoint: The value we want to Input to maintain -> target_rpm
 */
PID myPID(&measured_rpm, &pwm_rate, &target_rpm,Kp,Ki,Kd, DIRECT);

/**
 * Trigger a software reset on the Arduino by jumping to zero
 */
void(* triggerReset) (void) = 0; //declare reset function @ address 0

//////////////////////////////////////////////////////////////////
// Start of the program
//////////////////////////////////////////////////////////////////


/* Setup everything */
void setup() {

   Serial.begin(9600); // Let's not go too fast, otherwise we'll lose
                       // characters on long JSON input
   pinMode(pin1a,OUTPUT);
   pinMode(pin4a,OUTPUT);
   
#ifdef DEBUG
   pinMode(debugpin,OUTPUT);
#endif

   // Initialise our accessory map:
   for (int i=0; i<32; i++) {
     accessory_map[i]=false;
   };

   Timer1.initialize(1e6/PWMFREQUENCY);
   // enable timer compare interrupt
   TIMSK1 |= (1 << OCIE1A);
   TIMSK1 |= (1 << OCIE1B);

   //turn the PID on
   myPID.SetSampleTime(sampleTime);
   myPID.SetOutputLimits(0,MAX_PWM);
   myPID.SetMode(AUTOMATIC);

   // Initialize the ADC to a faster speed:
   // set up the ADC
   ADCSRA &= ~PS_128;  // This is the default Arduino prescaler, clear it
   ADCSRA |= PS_64;    // set our own prescaler to 64 (double speed)
   
   // Initialise the SPI library
   SPI.setBitOrder(MSBFIRST); // 33879 Uses MSB First transmission
   SPI.begin();
   SPI.setDataMode(SPI_MODE1); // Data on clock going down
   
   pinMode(spi_ss,OUTPUT);
   digitalWrite(spi_ss,HIGH); // Deselect chips
   delay(3);
   
   // SPI Integrity check: transmit 4 bytes to each chip. 1st byte received should be
   // zero, 2nd received byte is the fault output, 3rd & 4th are the same as byte 1 and
   // 2 we sent:
   digitalWrite(spi_ss,LOW);
   
   // Test pattern that will be sent to 2nd chip:
   byte val = SPI.transfer(0xaa); // Test pattern (10101010)
   // "val" should be zero (doc p17), coming from 2nd chip
   post_result |= (val!=0) ? SPI_INTEGRITY_FAULT : 0;
   val = SPI.transfer(0x55); // Test pattern (01010101)
   // "val" will be fault status of the outputs (we don't know what
   // it can be, we don't test)
   
   // Test pattern that will be sent to 1st chip
   val = SPI.transfer(0xaa); // Test pattern (10101010)
   // "val" should be zero (doc p17), coming from 1st chip
   post_result |= (val!=0) ? SPI_INTEGRITY_FAULT : 0;
   val = SPI.transfer(0x55); // Test pattern (01010101)
   // "val" will be fault status of the outputs of 1st chip

   // Now send second batch of values, those are the ones that
   // we be commands for the chips - in our case, switch off all
   // outputs, and turn off open load detect
   // Chip 2:
   val = SPI.transfer(0);
   // "val" should now be the 1st 0xaa we wrote:
   post_result |= (val!=0xaa) ? SPI_INTEGRITY_FAULT : 0;
   val = SPI.transfer(0);
   post_result |= (val!=0x55) ? SPI_INTEGRITY_FAULT : 0;

   // Chip 1:
   val = SPI.transfer(0);
   post_result |= (val!=0xaa) ? SPI_INTEGRITY_FAULT : 0;
   val = SPI.transfer(0);
   post_result |= (val!=0x55) ? SPI_INTEGRITY_FAULT : 0;

   // And wrap it up:
   digitalWrite(spi_ss,HIGH);

}

/**
 * Read ADC when PWM signal is low in order to measure the
 * motor's back EMF.
 *
 * Note: spending too much time in the interrupts leads to lost
 * characters on the serial input, therefore we need to make things
 * as fast as possible here. The interrupt must last less than two
 * characters (the length of the hardware UART buffer on the Arduino)
 *
 * COMPA is for Pin 9
 */
ISR(TIMER1_COMPA_vect){
  if (current_direction != FWD)
    return;
  delayMicroseconds(1300); // Wait for the filter curve to be past us.
  if (!bitRead(PINB,1))
  { // Only trigger when output goes low (measuring Back EMF)
#ifdef DEBUG
      setpin(PORTD,7);  // Just a debug signal for my scope to check
                        // how long it takes for the loop below to complete
#endif
      // Now read our analog pin (average over several samples, it is very noisy):
      int bemf = analogRead(bemfpin);
      for (int i=0; i<7;i++) {
         bemf += analogRead(bemfpin);
      }
      ring_buffer[idx] = bemf; // No overflow to fear, analog read is 0-1023.
      idx = (idx+1)%BUFFER_SIZE;
#ifdef DEBUG
      clearpin(PORTD,7);
#endif
    } else {
      // Measuring current, not voltage, since output is high
#ifdef DEBUG
      setpin(PORTD,7);
#endif
      int curr = analogRead(currentpin);
      for (int i=0; i<7;i++) {
         curr += analogRead(currentpin);
      }
      ring_buffer_current[idx2] = curr; // No overflow to fear, analog read is 0-1023.
      idx2 = (idx2+1)%BUFFER_SIZE;
#ifdef DEBUG
      clearpin(PORTD,7);
#endif
    }
}

/**
 * This is triggered for the other PWM output (pin 10)
 */
ISR(TIMER1_COMPB_vect){
  if (current_direction != BCK)
    return;
  delayMicroseconds(1300);
  if (!bitRead(PINB,2))
  { // Only trigger when output goes low
#ifdef DEBUG
      setpin(PORTD,7);
#endif
      int bemf = analogRead(bemfpin);
      for (int i=0; i<7;i++) {
         bemf += analogRead(bemfpin);
      }
      ring_buffer[idx] = bemf;
      idx = (idx+1)%BUFFER_SIZE;
#ifdef DEBUG
      clearpin(PORTD,7);
#endif
    } else {
#ifdef DEBUG
      setpin(PORTD,7);  // Just a debug signal for my scope to check
                        // how long it takes for the loop below to complete
#endif
      int curr = analogRead(currentpin);
      for (int i=0; i<7;i++) {
         curr += analogRead(currentpin);
      }
      ring_buffer_current[idx2] = curr; // No overflow to fear, analog read is 0-1023.
      idx2 = (idx2+1)%BUFFER_SIZE;
#ifdef DEBUG
      clearpin(PORTD,7);
#endif
    }
}

/**
 * Again, we have a _noisy_ signal, so a moving average over BUFFER_SIZE
 * samples is a must. Length of the moving average should remain under the PID
 * loop sample time.
 */
double moving_avg(double buffer[]) {
  double avg =0;
  for (int i=0; i< BUFFER_SIZE; i++) {
    // Note: we took 8 samples, but skipped the averaging
    // in the interrupt to save time, so we divide here:
    avg += buffer[i]/8;
  }
  return avg/BUFFER_SIZE;  
}
  

/**
 * Set PWM duty cycle
 */
void pwm(int val) {
  // We use setPwmDuty here because PWM is already initialized earlier.
  // and setPwmDuty is faster.
  switch (current_direction) {
    case FWD:
      Timer1.setPwmDuty(fwdpwm, val);
      break;
    case BCK:
      Timer1.setPwmDuty(bckpwm,val);
      break;
    default:
      break;
  }
}

/**
 * Nice utility to print free Ram
 * http://www.controllerprojects.com/2011/05/23/determining-sram-usage-on-arduino/
 * thanks!
 */
int freeRam () {
  extern int __heap_start, *__brkval; 
  int v; 
  return (int) &v - (__brkval == 0 ? (int) &__heap_start : (int) __brkval); 
}



// Using the fault register value and bank number,
// update our connected accessory map
void remap_faults(byte bank, byte faults) {
  byte v;
  for (int i=0; i<8; i++) {
    v = faults & (1<<i);
    if (bank%2) {
      accessory_map[bank*8+lowside_inverse_map[i]] = !(v>0);
    } else {
      accessory_map[bank*8+7-lowside_inverse_map[i]] = !(v>0);
    }
  }
}

/**
 * Switch a relay on-off.
 */
void relayCommand(int address, int op)
{
  byte response, io;
  if (address < 0|| address > RELAYS)
    return;
  address--; // Commands are 1 to 4, we translate from 0 to 3
  // Remap the relay outputs (PCB is not wired in order):
  address = relay_map[address];
  // Relay outputs are in port 5 to 8
  byte bankio = 1 << (address+4);
  if (op == RELAY_OFF) {
    relay_mask &= ~bankio;
  } else {
    relay_mask |= bankio;
  }
  
  // Enable the accessory bank (highside driver)
  digitalWrite(spi_ss,LOW);
  response = SPI.transfer(0);       // Disable open load detect for relays
  response = SPI.transfer(relay_mask); // Highside driver value
  response = SPI.transfer(0);      // Disable open load detect on low side.
  response = SPI.transfer(0);      // Lowside: all zeroes for now (all accessories off)
  digitalWrite(spi_ss,HIGH);       // Turn outputs on/off

}

/**
 * Set a turnout
 * Arguments: 
 * address: turnout number (starts at ONE)
 * dir: true or false (straight or not)
 * op : one of OP_PULSE, OP_LONGPULSE (for decouplers)
 */
void accessoryCommand(int address, int port, int op)
{
  byte response, io;
  address--; // we start at one in the command, this is more human friendly.
  // Compute the turnout bank we should enable
  byte bank = address / turnout_banks;
  byte bankio = (1 << highside_map[bank]) | relay_mask; // Preserve relay state too
  
  
  // Compute the actual I/O we should pulse
  if (bank%2) { // Ports are wired in a symetrical way on the board
    io = 1 << (lowside_map[address%turnout_banks*2+port]);
  } else {
    io = 1 << (lowside_map[7-address%turnout_banks*2-port]);
  }
  
    if (op == OP_ON) {
      // Save timestamp & accessory ID:
      accessory_on_id = address;
      accessory_on_port = port;
      accessory_on_timestamp = millis();
    }

   // Enable the accessory bank (highside driver)
   digitalWrite(spi_ss,LOW);
   response = SPI.transfer(0);      // 1st byte is Open load detect: we don't want it on high side
   response = SPI.transfer(bankio); // Highside driver value (bank select)
   response = SPI.transfer(0xff);   // Enable open load detect on low side.
   response = SPI.transfer(0);      // Lowside: all zeroes for now (all accessories off)
   digitalWrite(spi_ss,HIGH);       // Turn outputs on/off
   delay(10); // Required to give the 33880 time to do open circuit fault detection (has to be > 300us)
   // Send pulse (lowside driver)
   digitalWrite(spi_ss,LOW); // Upon transistion to low, fault status is udpated in the
                              // 33880 register: the next two SPI commands will return those,
                              // see below. 
   if (op != OP_OFF) {
     // Enable the lowside driver for the currently selected
     // accessory
     response = SPI.transfer(0);      // Disable open load detect on Hiside (response should be zero)
     response = SPI.transfer(bankio); // Highside driver value (response = hiside status)
     //Serial.print("Highside fault upon bank select: ");
     //Serial.println(response,BIN);
     response = SPI.transfer(0);      // Now disable open load detect on lowside, saves power
                                      // response should be zero
     response = SPI.transfer(io);     // Lowside driver value
     // This response value tells up which pins are connected to
     // an accessory and which are not:
     // a connected pin will be zero, an unconnected one will be 1 ("Open")
     remap_faults(bank,response);

#if 0
    aJsonObject *msg = aJson.createObject();
    aJson.addNumberToObject(msg, "bank", bank);
    aJson.addNumberToObject(msg, "bankio", bankio);
    aJson.addNumberToObject(msg, "io", io);    
    aJson.addNumberToObject(msg, "faults", response);
    aJson.print(msg, &serial_stream);
    Serial.println();
    aJson.deleteItem(msg);
#endif

   }
    if (op == OP_PULSE) {
        digitalWrite(spi_ss,HIGH);    // Updates outputs + fault status
        delay(turnoutPulse);
        digitalWrite(spi_ss,LOW);
   }
   if (op != OP_ON) {
     response = SPI.transfer(0);
     response = SPI.transfer(relay_mask);      // Switch off Highside (preserve relays)
     //response is now Highside fault status after lowside select
     response = SPI.transfer(0);
     response = SPI.transfer(0);      // Switch off Lowside
     //response is now Lowside fault status after lowside select
   }
   digitalWrite(spi_ss,HIGH);
}
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
void loop() {
  
  ///////
  // Regular serial port output
  ///////  
  if (millis() - last_print > updateRate) {
    aJsonObject *msg = createMessage();
    aJson.print(msg, &serial_stream);
    Serial.println();
    aJson.deleteItem(msg);
    last_print = millis();
  }

  ///////
  // Safeguard: switch off an accessory that remained
  // on for too long
  ///////
  if (accessory_on_id > -1) {
    if (millis() - accessory_on_timestamp > turnoutMaxOn) {
        accessoryCommand(accessory_on_id,accessory_on_port, OP_OFF);
        accessory_on_id = -1;
    }
  }
 
  ///////
  // PID calculations
  ///////  
   measured_rpm = moving_avg(ring_buffer);
   myPID.Compute(); // Most important part!
   pwm(pwm_rate);

  ///////
  // Measure current too
  ///////
  measured_current = moving_avg(ring_buffer_current);

  ///////
  // Process incoming commands
  ///////  
  if (serial_stream.available()) {
    aJsonObject *msg = aJson.parse(&serial_stream);
    if (!msg) {
      // We were not able to decode this, let's
      // simply flush the buffer and go on with our
      // life
      serial_stream.flush();
      next_message = MSG_JSON_SYNTAX;
    } else {
      processMessage(msg);
      aJson.deleteItem(msg);
    }
  }
 
}

/**
 * Transition to new speed
 */
void change_speed(int new_speed, int stp) {
  if (new_speed < pwm_rate)
    stp = - stp;
  while (abs(new_speed-pwm_rate) > abs(stp)) {
    pwm_rate += stp;
    pwm(pwm_rate);
    delay(15);
  }
  pwm_rate = new_speed;
  pwm(pwm_rate);
}

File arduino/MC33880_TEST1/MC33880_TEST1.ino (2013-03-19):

/**
 * This is a test for Freescale 33880 SPI relay drivers
 * (c) Ed Lafargue 2013
 * Licence: GPLv3
 *
 * 2013.03.17: Simple test for a single chip
 */
 
/* The hardware SPI library is used to control turnouts */
#include <SPI.h>


//////////////////////////////////////////////////////////////////
// Enable Debug mode
//////////////////////////////////////////////////////////////////
#define DEBUG

//////////////////////////////////////////////////////////////////
// Hardware pinout info
//////////////////////////////////////////////////////////////////

// SPI Connection to the shift register/relay driver
const int spi_mosi  = 11;
const int spi_miso  = 12;
const int spi_clock = 13;
const int spi_ss = 6;


//////////////////////////////////////////////////////////////////
// Global constants and defines
//////////////////////////////////////////////////////////////////

int accessory_on_id;
int accessory_on_port;
int accessory_on_timestamp;

// Define two set/clear macros to do PIN manipulation
// way way faster than Arduino's digitalWrite.
// inspired by the the _BV() macro
#define setpin(port, pin) (port) |= (1 << (pin)) 
#define clearpin(port, pin) (port) &= ~(1 << (pin))

// Turnout control below

#define OP_PULSE 0
#define OP_ON 1
#define OP_OFF 2


const int turnout_max   = 16; // 2x 74HC595 + ULN2083A low side driver
const int turnout_banks =  4; // We have 4 banks of 4 turnouts

// In order to simplify PCB layout, I used MC33880 pins out of order,
// so I'm using a static mapping array to remap the pins for both
// turnouts and banks:
// Turnout bank mapping: what pin matches what port
//                  Port:    0    1    2    3    4   5   6   7 
//const byte lowside_map[] = {  7,   3,   2,   4,   7,  1,  0,  5 };
const byte lowside_map[] = {  0,   1,   2,   3,   4,  5,  6,  7 };

// Turnout pinout mapping
//                  Port:    0    1    2    3
//const int highside_map[] = {  1,   0,   2,   3};
const byte highside_map[] = {  0,   1,   2,   3};

// Fault map: for bank 1 to 4 (lowside), a bit in a bank's byte means
//            we have an open circuit.
//    Note: remapped to natural order (or is it? to be confirmed)
byte fault_map[] = {0,0,0,0};

// Default length of Turnout set pulse (in ms):
int turnoutPulse = 20;
// Default maximum "on" time for accessory
int turnoutMaxOn = 2000;

unsigned long last_print;
int updateRate = 500;

//////////////////////////////////////////////////////////////////
// Start of the program
//////////////////////////////////////////////////////////////////

/* Setup everything */
void setup() {

   Serial.begin(9600); // Let's not go too fast, otherwise we'll lose
                       // characters on long JSON input
   
   // Initialise the SPI library
   SPI.setBitOrder(MSBFIRST); // 33880 Uses MSB First transmission
   SPI.begin();
   SPI.setDataMode(SPI_MODE1);
   
   pinMode(spi_ss,OUTPUT);
   digitalWrite(spi_ss,HIGH); // Deselect chips
   delay(3);
   
   // SPI Integrity check: transmit 2 bytes to each chip. 1st received byte is the
   // fault output, 2nd received byte should be same as 1st sent byte
   digitalWrite(spi_ss,LOW);
   byte val = SPI.transfer(0xaa); // Test pattern (10101010)
   Serial.print("1st startup byte (old data highside): ");
   Serial.println(val);
   val = SPI.transfer(0xaa); // All outputs off
   Serial.print("2nd startup byte (old data lowside: ");
   Serial.println(val);
   val = SPI.transfer(0); 
   Serial.print("3rd startup byte (Test hiside, should be 170): ");
   Serial.println(val);
   val = SPI.transfer(0);
   Serial.print("3rd startup byte (Test lowside, should be 170): ");
   Serial.println(val);
   digitalWrite(spi_ss,HIGH);
   
   delay(2000);
   
}


/**
 * Set a turnout
 * Arguments: 
 * address: turnout number (starts at zero)
 * dir: true or false (straight or not)
 * op : one of OP_PULSE, OP_ON, OP_OFF
 */
boolean accessoryCommand(int address, int port, int op)
{
  byte response;
  // Compute the turnout bank we should enable
  // TODO (not on hardware prototype yet)
  byte bank = address / turnout_banks;
  byte bankio = 1 << highside_map[bank];
  Serial.println("-----------");
  Serial.print("Bank pin: ");
  Serial.println(bankio);
  
  // Compute the actual I/O we should pulse
  int io = 1 << (lowside_map[address%turnout_banks*2]);
  io = io << port;

    if (op == OP_ON) {
      // Save timestamp & accessory ID:
      accessory_on_id = address;
      accessory_on_port = port;
      accessory_on_timestamp = millis();
    }

   // Enable the accessory bank (highside driver)
   digitalWrite(spi_ss,LOW);
   response = SPI.transfer(bankio); // Highside driver value (bank select)
   response = SPI.transfer(0);      // Lowside: all zeroes for now (all accessories off)
   digitalWrite(spi_ss,HIGH); // Upon transistion to high, fault status is udpated in the
                              // 33880 register: the next two SPI commands will return those,
                              // see below.   
   delay(1); // Required to give the 33880 time to do open circuit fault detection (has to be > 300us)
   // Send pulse (lowside driver)
   digitalWrite(spi_ss,LOW);
   if (op != OP_OFF) {
     Serial.print("Lowside select value: ");
     Serial.println(io);
     response = SPI.transfer(bankio); // Highside driver value
     Serial.print("Highside fault upon bank select: ");
     Serial.println(response,BIN);
     response = SPI.transfer(io);     // Lowside driver value
     // This response value tells up which pins are connected and which are not:
     // a connected pin will be zero, an unconnected one will be 1 ("Open")
     fault_map[bank] = response;
     Serial.print("Lowside fault upon bank select: ");
     Serial.println(response,BIN);
   }
    if (op == OP_PULSE) {
        digitalWrite(spi_ss,HIGH);    // Update outputs + fault status
        delay(turnoutPulse);
        digitalWrite(spi_ss,LOW);
   }
   if (op != OP_ON) {
     response = SPI.transfer(0);      // Switch off Highside
     Serial.print("Highside fault after lowside select: ");
     Serial.println(response,BIN);
     response = SPI.transfer(0);      // Switch off Lowside
     Serial.print("Lowside fault after lowside select: ");
     Serial.println(response,BIN);

   }
   digitalWrite(spi_ss,HIGH);

}


/**
 *  The main loop, which processes incoming data, outputs data
 * and updates the PID loop.
 */
void loop() {
  
    accessoryCommand(0,0,0);
    delay(800);
    accessoryCommand(0,1,0);
    delay(800); 
   accessoryCommand(1,0,0);
    delay(800);
 
}

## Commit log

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2013-02-08 JSON and Hardware schematics
    This is untested so far. Added JSON support for both input and output
    on the controller, added simple schematics of the controller, updated
    .gitignore to exclude Eagle backup files.
    [controller v1.brd, controller v1.sch]
2013-02-09 Working version of JSON interface
    The Arduino board tends to lose characters on the serial input,
    so more work is needed to make it more reliable. But it already
    works quite well.
2013-02-09 Update to aJson library
    Use a 1 second timeout on getch as a fallback in case the parser
    is lost. No more crashes!
2013-02-09 Lowered default speed, added free ram debug output
    Now seems to reliably get commands every time, since interrupts
    are now faster and serial speed slower. Also debugs the amount of
    free RAM in output if "DEBUG" is defined.
2013-02-13 Further work and bugfixing
    Found a stray global variable in one file which introduced hard to
    track bugs, corrected now.
2013-02-14 Home screen views display layout and loco
    Last night's work: home screen displays display, controller UI
    on home screen, loco info sub-view. Now the next step is actually
    hooking up socket.io and talk to the controller.
2013-02-22 First actually working version.
    Tested on real layout, it is working fine. Controller power slider fill varies
    with power adjustment done by PID controller to provide visual feedback on how
    the PID is working. All views seem to be working fine.
    Still need to implement robust controller port handling, locomotive runtime
    monitoring, and locomotive response logging for long term performance monitoring.
2013-02-22 Bug fixes
    - When adding a new logo and selecting the picture at the same time
    the picture was called "undefined" instead of loco Id. Fixed
    - Adding a new loco was not working because of reference to _id in
    template.
    - Removed references to localhost in all socket.io calls.
2013-02-24 First properly running version
    - Loco thumbnail is clickable on the main page and opens a lightbox
    - Power slider is touch compatible for use on mobile devices
    - Acknowledge from server for sucessful connection to controller
    - Power slider is skinned
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2013-02-27 Add confirm delete button on both loco and layout managers
    Used bootbox.js as a helper library.
2013-03-01 Refactor: create a link manager to manage socket.io connection
    Now all views will refer to the link manager instead of the socket, and
    call higher level functions. This will enable the link manager to translate
    commands into the correct protocol over the socket.io link as well as share
    state information.
    Also: bug fix for dates, and automated dropdown generation of all dates
    in the loco edit template. Preliminary work for Controller PID settings
    adjustment. Preliminary work for loco maintenance log.
2013-03-01 Switch to FuelUX as widget library, remove jQuery UI entirely
    FuelUX is an extension to Bootstrap and contains bootstrap. Used
    so far to create nice spinner controls for the PID settings.
    Also removed dependencies on jQueryUI which does not play nice with
    Bootstrap/FuelUX and implemented custom power slider (no handle for now
    I like it that way).
2013-03-01 Bug fix: switch to FuelUX caused edit loco and layout to fail.
    Also small progress on PID settings UI
2013-03-04 Further work on PID settings UI
    Finally managed to make the layout details spinner controls work fine,
    the bootstrap-spinedit library is not very easy to use - returns
    string values for numbers...
2013-03-04 Arduino sketch update: add command ack name
    The arduino controller now adds the command name to ack packets
    so that the server knows what it is acknowledging for.
2013-03-04 PID settings support
    Controller PID settings can be read/saved/modified, including while
    running. Updated link Manager to use built-in Backbone events rather
    than my own class.
2013-03-05 Add touch support for power control slider
    Now works fine with finger drag - and page does not scroll -
2013-03-05 Bugfix - when power=0, progress slider did not get updated
    was testing for value, not for isNaN...
2013-03-05 Link establishment more robust
    The server now waits until it gets a steady flow of json input
    before sending a "link established" message. "Connect" button on the
    front end uses "warning" color while trying to connect. Various bugfixes.
2013-03-05 Correct typo in arduino sketch comment...
    [L293D_BACKEMF_BIDIRECTIONAL_PID.ino]
2013-03-07 Implement turnout control on Arduino sketch and further work on web app
    Added SPI support on Arduino sketch, along with set/query commands to
    control turnouts. Not fully tested yet. Further work on web app to support
    selecting the turnout/accessory address based on actual number of addresses
    supported on the controller.
2013-03-08 Bugfixing arduino sketch
    Latch values were wrong earlier.
    [L293D_BACKEMF_BIDIRECTIONAL_PID_TURNOUTS.ino]
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2013-03-08 Improvements on layout edit view.
    Pressing "Enter" on a modal now triggers the default function (blue button)
    rather than just close the modal and do nothing. Fixed error in new accessory
    creation.
2013-03-12 Update on hardware schematics for Arduino shield
    Final version will probably be a Beaglebone shield rather than Arduino,
    but Arduino is so simple for testing...
    [controller v1.brd, controller v1.sch]
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2013-03-18 Big bugfix on hardware controller schematics and board.
    The 33880 pinout was reversed on my schematics...
    [controller v1.brd, controller v1.sch]
2013-03-19 Test Arduino sketch for MC33880 testing.
    Works fine, using two MC33880 in highside/lowside config. Prototype
    full controller software updated to MC33880 support too. Not tested.
    Cosmetic fixes on schematics.
    [controller v1.sch]
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2013-03-20 Update on board layout for Arduino shield.
    Better layout, added component names.
    [controller v1.brd, controller v1.sch]
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2013-03-22 Diagnostics screen works now!
    Complete board diagnostics, including port open circuit detection.
    [controller v1.brd, controller v1.sch]
2013-03-23 V1.0 Hardware - Arduino Shield as ordered on Seeed Studio
    Added the Eagle + Gerbers ordered on Seeed Studio - not tested yet
    obviously.
    [controller v1.brd, controller v1.sch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]
2013-03-23 Added license/author into on schematics
    [controller v1.sch]
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2013-04-08 Start of Beaglebone cape
    [controller v2.brd, controller v2.sch]
2013-04-09 Disable port diags if POST result is Fail for SPI
2013-04-15 Updates to match exactly first working prototype
    [controller v1.brd, controller v1.sch]
2013-04-15 Another slight update for component values
    [controller v1.brd, controller v1.sch]
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2013-05-13 Add an option to reverse accessory ports in the accessory settings
    ... easier than require the user to swap the wires.
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2013-05-14 Add support for current sensor.
    All values output by the controller are now in real units (mV for BEMF
    and mA for current). Web app graphs current value. Better graphs (no
    gaps when sending turnout commands).
    [controller v1.brd, controller v1.sch]
2013-05-15 Bugfixes on both Arduino sketch & loco run view
    [L293D_BACKEMF_BIDIRECTIONAL_PID_TURNOUTS_33880_CURRENT.ino]
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2013-06-26 Hardware controller: Beaglebone cape
    This is the working design - v3.0. Not fully debugged yet, but seems
    to be working fine so far.
    [controller v3.brd, controller v3.sch]
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2013-08-04 Various updates and bug fixes
    [L293D_BACKEMF_BIDIRECTIONAL_PID_TURNOUTS_33879_CURRENT.ino]
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2013-08-04 Relay query in accessory view: bugfixes
2015-03-17 Node-serialport fixes for current version.
2015-03-18 Arduino Sketch: fix auto accessory off (was not working properly, and accessories remained on forever).
    [L293D_BACKEMF_BIDIRECTIONAL_PID_TURNOUTS_33879_CURRENT.ino]
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2022-04-10 Raspberry Pi adapter board to make the controller compatible with RPi 3
    [Pi Adapter 3-B_Cu.gbl, Pi Adapter 3-B_Mask.gbs, Pi Adapter 3-B_Silkscreen.gbo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]
2025-08-16 Full upgrade (#2)
    * Claude: upgrade to Bootstrap 5, step 1
    * More updates to HTML templates
    * Further migration work
    * Restore proper views for the layout/loco/car lists
    * Fix picture upload
    * Add "Change Image" button for manual upload of images
    * Restore ability to select a layout
    * Restore ability to select a locomotive
    * Improve accessory details view
    * Restore accessory layout in the layout details view
    * Add more bootstrap 5 upgrades
    * Dark/Light mode support
    * Start of theme support
    * Working theme support
    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

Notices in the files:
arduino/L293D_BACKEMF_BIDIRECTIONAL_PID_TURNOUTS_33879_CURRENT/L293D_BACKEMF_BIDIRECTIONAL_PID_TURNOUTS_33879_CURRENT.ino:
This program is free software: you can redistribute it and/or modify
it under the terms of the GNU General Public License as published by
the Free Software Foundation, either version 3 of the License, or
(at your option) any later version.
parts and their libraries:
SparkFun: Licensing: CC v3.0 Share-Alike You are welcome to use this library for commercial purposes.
